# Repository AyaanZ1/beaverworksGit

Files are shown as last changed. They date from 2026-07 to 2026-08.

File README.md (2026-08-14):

# beaverworksGit

A maze-navigating robot built around an Arduino Mega 2560, combining custom
PCB design (KiCad) with firmware for grid-based autonomous navigation,
sensor logging, and ESP32-CAM video streaming.

## Overview

The robot drives through a 5x5 grid maze along a pre-defined path, correcting
its heading with an IMU (gyro yaw tracking) instead of relying on open-loop
timing alone. At each cell it pauses to read temperature, humidity, and
distance-to-obstacle, then reports the data back over serial. A light sensor
and buzzer provide simple flashlight/alarm behavior along the way, and a
separate ESP32-CAM module streams live video.

## Repository Structure

```
.
├── beaverworksGit.kicad_pro/.kicad_sch/.kicad_pcb  # KiCad project (schematic + PCB layout)
├── fp-lib-table                                    # KiCad footprint library table
├── hardware/                                        # Hardware design files
│   ├── beaverworksGit.kicad_*                       #   (duplicate/working copy of the KiCad project)
│   ├── Arduino Mega 2560 Rev3 A000067/               #   Arduino Mega 3D model + footprint
│   ├── Arduino_MountingHole.pretty/                  #   Mounting hole footprints
│   ├── HC-SR04 Model by SparkFun/                    #   Ultrasonic sensor 3D model + footprint
│   └── esp32-wrover-kicad-master/                    #   ESP32-WROVER KiCad library (third-party)
├── software/                                        # Firmware / companion scripts
│   ├── IMU Navigation/
│   │   ├── ObstacleAvoidance.ino                     #   Standalone obstacle-avoidance sketch
│   │   ├── Calibration/calibration.ino                #   IMU/gyro calibration routine
│   │   └── Yaw Tracking/mpu6050_copy_*/               #   MPU6050 yaw-tracking test sketch
│   ├── ESP32_Camera/                                 #   ESP32-CAM web server + streaming
│   │   ├── CameraWebServer.ino                        #     Main camera sketch (based on Espressif's CameraWebServer example)
│   │   ├── app_httpd.cpp / camera_pins.h / ...         #     Supporting camera server code
│   │   ├── wifi_secrets.example.h                     #     Template for Wi-Fi credentials (copy to wifi_secrets.h)
│   │   ├── record_video.py / stream_test.py            #     Python helpers for grabbing/testing the video stream
│   │   └── python/                                     #     Additional Python utilities
│   └── Sensors_Code/                                 #   (sensor test code)
├── main.cpp                                          # Main robot firmware: timed turns/drives, no gyro
├── navigatio.cpp                                     # Main robot firmware: gyro-corrected turns/drives (MPU6050)
└── platformio.ini                                    # PlatformIO project config (Arduino Mega target)
```

## Hardware

- **MCU:** Arduino Mega 2560 Rev3
- **IMU:** Adafruit MPU6050 (gyro-based yaw tracking)
- **Distance sensing:** HC-SR04 ultrasonic sensor
- **Environmental sensing:** DHT11 temperature/humidity sensor
- **Other I/O:** LDR (light sensor), sound sensor, buzzer, status LED
- **Drive:** Dual DC motors via an H-bridge driver (enable + direction pins per side)
- **Camera:** Separate ESP32-CAM module for live video streaming
- **PCB:** Custom board designed in KiCad (see `beaverworksGit.kicad_pro` / `hardware/`)

## Firmware

There are two versions of the main navigation firmware:

| File | Description |
|---|---|
| `main.cpp` | Drives a fixed sequence of grid moves using timed turns and timed straight-line driving (open-loop, no IMU feedback). |
| `navigatio.cpp` | Same grid path, but uses the MPU6050 gyro to track yaw in real time and correct heading while turning and driving (closed-loop). |

Both firmware versions:
1. Follow a hard-coded `path[]` array of `NORTH`/`EAST`/`SOUTH`/`WEST` moves through a 5x5 grid.
2. Stop at each cell to read temperature, humidity, and ultrasonic distance, and report them over serial.
3. Continuously monitor light and sound sensors to trigger an LED "flashlight" and buzzer alert.
4. Stop and idle once the path is complete.

### Building with PlatformIO

The project is set up for [PlatformIO](https://platformio.org/) targeting the Arduino Mega:

```bash
# Build
pio run

# Upload to the board
pio run -t upload

# Open the serial monitor (9600 baud)
pio device monitor
```

Dependencies (declared in `platformio.ini`):
- `adafruit/Adafruit MPU6050`
- `adafruit/Adafruit Unified Sensor`
- `adafruit/DHT sensor library`

> Note: only one of `main.cpp` / `navigatio.cpp` should be treated as the active
> `src/main.cpp` for a given build — move/copy whichever version you want to
> flash into PlatformIO's `src/` directory (or update `platformio.ini`'s
> `build_src_filter` accordingly).

### ESP32-CAM streaming

`software/ESP32_Camera/CameraWebServer.ino` is based on the standard Espressif
CameraWebServer example, adapted with local board/pin config. To use it:

1. Copy `wifi_secrets.example.h` to `wifi_secrets.h` and fill in your Wi-Fi
   SSID and password.
2. Flash `CameraWebServer.ino` to an ESP32-CAM board via the Arduino IDE
   (select the correct board and partition scheme — see `partitions.csv`).
3. Use `stream_test.py` or `record_video.py` to test/capture the resulting
   MJPEG stream from a computer on the same network.

### IMU navigation experiments

`software/IMU Navigation/` contains standalone sketches used during
development:
- `Calibration/calibration.ino` — computes gyro bias for the MPU6050.
- `Yaw Tracking/mpu6050_copy_*/` — isolated yaw-tracking test.
- `ObstacleAvoidance.ino` — simple reactive obstacle-avoidance behavior.

## Hardware Design (KiCad)

Open `beaverworksGit.kicad_pro` in [KiCad](https://www.kicad.org/) to view or
edit the schematic (`.kicad_sch`) and PCB layout (`.kicad_pcb`). Third-party
footprints/3D models used in the design are vendored under `hardware/`
(Arduino Mega, HC-SR04, ESP32-WROVER, mounting holes).

## Status

This is a work-in-progress class/competition project (Beaverworks). Firmware
constants such as `MS_PER_INCH`, `MS_PER_90_TURN`, drive speeds, and the
maze `path[]` are tuned for a specific physical maze layout and will need
recalibrating for a different course or robot chassis.

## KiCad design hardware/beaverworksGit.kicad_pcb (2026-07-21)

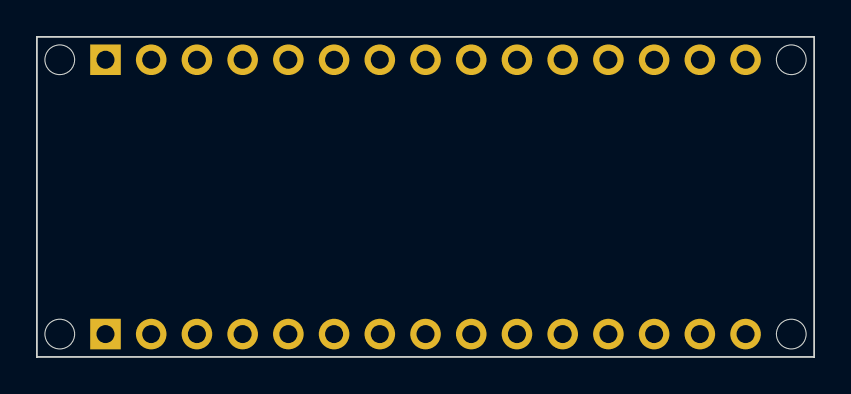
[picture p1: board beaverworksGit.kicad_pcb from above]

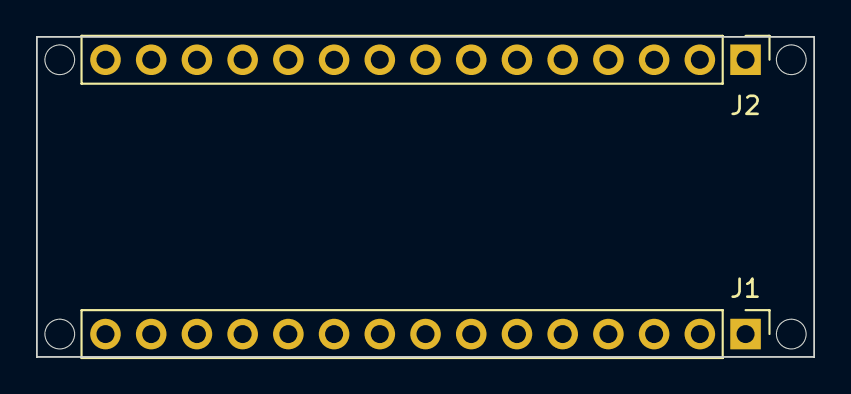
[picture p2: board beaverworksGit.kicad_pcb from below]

Board: 2 copper layers, 43.2 x 17.8 mm, 6 parts (2 on the bottom side), 2 nets, no tracks yet.

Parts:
J1: Analog; PinHeader_1x15_P2.54mm_Vertical
J2: Digital; PinHeader_1x15_P2.54mm_Vertical
MH1, MH2, MH3, MH4: MountingHole_65mil

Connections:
/~RESET: J1.13, J2.13
GND: J1.14, J2.12

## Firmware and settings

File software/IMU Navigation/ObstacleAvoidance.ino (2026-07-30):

#include <Arduino.h>
#include <Servo.h>

// ============================================================
// CONFIRMED MOTOR WIRING
// ============================================================
const byte LEFT_EN  = 2;
const byte LEFT_IN1 = 22;
const byte LEFT_IN2 = 23;

const byte RIGHT_EN  = 3;
const byte RIGHT_IN1 = 24;
const byte RIGHT_IN2 = 25;

// ============================================================
// ULTRASONIC + SERVO
// ============================================================
const byte TRIG_PIN  = 12;
const byte ECHO_PIN  = 13;
const byte SERVO_PIN = 4;   // Must not be pin 3

Servo scanServo;

// Change LEFT_ANGLE and RIGHT_ANGLE only if your servo is mounted backward.
const int LEFT_ANGLE    = 180;
const int CENTER_ANGLE  = 90;
const int RIGHT_ANGLE   = 0;

// ============================================================
// NAVIGATION SETTINGS
// ============================================================
const int DRIVE_SPEED = 150;
const int TURN_SPEED  = 150;

const int OBSTACLE_DISTANCE_CM = 25;
const int SIDE_CLEARANCE_CM    = 20;

// Calibrate this after basic behavior works.
const unsigned long TURN_90_TIME_MS = 650;
const unsigned long REVERSE_TIME_MS = 350;

const unsigned long SERVO_SETTLE_MS = 500;

// ============================================================
// MOTOR CONTROL
// Positive speed = forward
// Negative speed = reverse
// ============================================================
void setLeftMotor(int speed) {
  speed = constrain(speed, -255, 255);

  if (speed > 0) {
    digitalWrite(LEFT_IN1, HIGH);
    digitalWrite(LEFT_IN2, LOW);
  } else if (speed < 0) {
    digitalWrite(LEFT_IN1, LOW);
    digitalWrite(LEFT_IN2, HIGH);
  } else {
    digitalWrite(LEFT_IN1, LOW);
    digitalWrite(LEFT_IN2, LOW);
  }

  analogWrite(LEFT_EN, abs(speed));
}

void setRightMotor(int speed) {
  speed = constrain(speed, -255, 255);

  if (speed > 0) {
    digitalWrite(RIGHT_IN1, HIGH);
    digitalWrite(RIGHT_IN2, LOW);
  } else if (speed < 0) {
    digitalWrite(RIGHT_IN1, LOW);
    digitalWrite(RIGHT_IN2, HIGH);
  } else {
    digitalWrite(RIGHT_IN1, LOW);
    digitalWrite(RIGHT_IN2, LOW);
  }

  analogWrite(RIGHT_EN, abs(speed));
}

void moveForward() {
  setLeftMotor(DRIVE_SPEED);
  setRightMotor(DRIVE_SPEED);
}

void moveBackward() {
  setLeftMotor(-DRIVE_SPEED);
  setRightMotor(-DRIVE_SPEED);
}

void stopMotors() {
  setLeftMotor(0);
  setRightMotor(0);
}

void pivotLeft() {
  setLeftMotor(-TURN_SPEED);
  setRightMotor(TURN_SPEED);
}

void pivotRight() {
  setLeftMotor(TURN_SPEED);
  setRightMotor(-TURN_SPEED);
}

// ============================================================
// ULTRASONIC READING
// ============================================================
long singleDistanceReading() {
  digitalWrite(TRIG_PIN, LOW);
  delayMicroseconds(3);

  digitalWrite(TRIG_PIN, HIGH);
  delayMicroseconds(10);
  digitalWrite(TRIG_PIN, LOW);

  unsigned long duration = pulseIn(ECHO_PIN, HIGH, 30000UL);

  // No echo generally means nothing is nearby.
  if (duration == 0) {
    return 400;
  }

  long distanceCm = duration * 0.0343 / 2.0;

  if (distanceCm < 2 || distanceCm > 400) {
    return 400;
  }

  return distanceCm;
}

// Take three readings and return the median.
// This rejects many random HC-SR04 spikes.
long readDistanceCM() {
  long a = singleDistanceReading();
  delay(25);

  long b = singleDistanceReading();
  delay(25);

  long c = singleDistanceReading();

  if (a > b) {
    long temp = a;
    a = b;
    b = temp;
  }

  if (b > c) {
    long temp = b;
    b = c;
    c = temp;
  }

  if (a > b) {
    long temp = a;
    a = b;
    b = temp;
  }

  return b;
}

long lookAt(int angle) {
  scanServo.write(angle);
  delay(SERVO_SETTLE_MS);

  long distance = readDistanceCM();

  Serial.print("Servo angle ");
  Serial.print(angle);
  Serial.print(" -> ");
  Serial.print(distance);
  Serial.println(" cm");

  return distance;
}

// ============================================================
// TURNING
// ============================================================
void turnLeft90() {
  Serial.println("ACTION: TURN LEFT");

  pivotLeft();
  delay(TURN_90_TIME_MS);

  stopMotors();
  delay(250);
}

void turnRight90() {
  Serial.println("ACTION: TURN RIGHT");

  pivotRight();
  delay(TURN_90_TIME_MS);

  stopMotors();
  delay(250);
}

// ============================================================
// OBSTACLE AVOIDANCE
// ============================================================
void avoidObstacle() {
  stopMotors();
  delay(250);

  Serial.println();
  Serial.println("OBSTACLE DETECTED — SCANNING");

  long leftDistance = lookAt(LEFT_ANGLE);
  long rightDistance = lookAt(RIGHT_ANGLE);

  scanServo.write(CENTER_ANGLE);
  delay(SERVO_SETTLE_MS);

  Serial.print("LEFT: ");
  Serial.print(leftDistance);
  Serial.print(" cm | RIGHT: ");
  Serial.print(rightDistance);
  Serial.println(" cm");

  bool leftBlocked = leftDistance <= SIDE_CLEARANCE_CM;
  bool rightBlocked = rightDistance <= SIDE_CLEARANCE_CM;

  // Both sides blocked: back away, then turn toward the larger opening.
  if (leftBlocked && rightBlocked) {
    Serial.println("Both sides blocked — reversing");

    moveBackward();
    delay(REVERSE_TIME_MS);
    stopMotors();
    delay(200);
  }

  // Turn toward the side with MORE space.
  if (leftDistance > rightDistance) {
    turnLeft90();
  } else {
    turnRight90();
  }

  // Always center the sensor after turning.
  scanServo.write(CENTER_ANGLE);
  delay(250);
}

// ============================================================
// SETUP
// ============================================================
void setup() {
  Serial.begin(9600);

  pinMode(LEFT_EN, OUTPUT);
  pinMode(LEFT_IN1, OUTPUT);
  pinMode(LEFT_IN2, OUTPUT);

  pinMode(RIGHT_EN, OUTPUT);
  pinMode(RIGHT_IN1, OUTPUT);
  pinMode(RIGHT_IN2, OUTPUT);

  pinMode(TRIG_PIN, OUTPUT);
  pinMode(ECHO_PIN, INPUT);

  stopMotors();

  scanServo.attach(SERVO_PIN);
  scanServo.write(CENTER_ANGLE);

  delay(1500);

  Serial.println("Obstacle avoidance started.");
}

// ============================================================
// MAIN LOOP
// ============================================================
void loop() {
  scanServo.write(CENTER_ANGLE);

  long frontDistance = readDistanceCM();

  Serial.print("FRONT: ");
  Serial.print(frontDistance);
  Serial.println(" cm");

  if (frontDistance > OBSTACLE_DISTANCE_CM) {
    moveForward();
  } else {
    avoidObstacle();
  }

  delay(60);
}

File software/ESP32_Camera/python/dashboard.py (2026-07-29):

import time
from collections import deque
from pathlib import Path

import cv2
import streamlit as st
import pandas as pd
import requests
from ultralytics import YOLO


STREAM_URL = "http://192.168.1.4:81/stream"
CELL_URL = "http://192.168.1.4/cell"
MODEL_PATH = Path(__file__).parent / "yolo26n.pt"

TARGET_CLASS = "person"
CONFIRMATION_FRAMES = 3
TARGET_LOSS_DELAY = 0.75

HEAT_HAZARD_THRESHOLD_C = 35.0

IMAGE_DIRECTORY = Path(__file__).parent / "cell_images"
IMAGE_DIRECTORY.mkdir(parents=True, exist_ok=True)

CELL_POLL_INTERVAL = 0.5


st.set_page_config(
    page_title="Autonomous Robot Dashboard",
    page_icon="🤖",
    layout="wide",
)

if "detection_log" not in st.session_state:
    st.session_state.detection_log = []

if "selected_cell_id" not in st.session_state:
    st.session_state.selected_cell_id = 1

if "last_reported_cell_id" not in st.session_state:
    st.session_state.last_reported_cell_id = None

if "pending_capture_cell_id" not in st.session_state:
    st.session_state.pending_capture_cell_id = None


def create_empty_cell_data():
    """Create 16 empty cells that are populated by live ESP32 readings."""
    cells = {}

    for cell_id in range(1, 17):
        cells[cell_id] = {
            "id": cell_id,
            "tempC": None,
            "heatHazard": False,
            "humidity": None,
            "distanceCm": None,
            "soundLevel": None,
            "soundHazard": False,
            "ok": True,
            "visited": False,
            "latest_image": None,
            "objects": [],
        }

    return cells
def format_reading(value, decimals=1, suffix=""):
    """Display unavailable sensor readings as --."""
    if value is None:
        return "--"

    return f"{value:.{decimals}f}{suffix}"


def format_temperature(temp_c):
    """Display temperature in Celsius and Fahrenheit."""
    if temp_c is None:
        return "--"

    temp_f = temp_c * 9 / 5 + 32
    return f"{temp_c:.1f}°C ({temp_f:.1f}°F)"


def update_live_cell_data():
    """Fetch the newest environmental reading from the ESP32."""

    try:
        response = requests.get(CELL_URL, timeout=0.25)

        if response.status_code != 200:
            return

        live = response.json()

        cell_id = live["id"]

        if cell_id not in st.session_state.cell_data:
            return

        st.session_state.cell_data[cell_id].update(
            {
                "id": cell_id,
                "tempC": live["tempC"],
                "heatHazard": (
                    live["tempC"] is not None
                    and live["tempC"] >= HEAT_HAZARD_THRESHOLD_C
                ),
                "humidity": live["humidity"],
                "distanceCm": live["distanceCm"],
                "soundLevel": live.get("soundLevel"),
                "soundHazard": live.get("soundHazard", False),
                "ok": live["ok"],
                "visited": True,
            }
        )

        if cell_id != st.session_state.last_reported_cell_id:
            st.session_state.last_reported_cell_id = cell_id
            st.session_state.pending_capture_cell_id = cell_id

    except Exception:
        pass


if "cell_data" not in st.session_state:
    st.session_state.cell_data = create_empty_cell_data()
update_live_cell_data()

st.title("🤖 Autonomous Robot Dashboard")
st.caption("Real-time perception, navigation, and environmental monitoring")


@st.cache_resource
def load_model(model_path: str) -> YOLO:
    return YOLO(model_path)


def choose_command(
    center_x: float,
    frame_width: int,
    box_width: float,
) -> str:
    left_boundary = frame_width * 0.40
    right_boundary = frame_width * 0.60
    width_ratio = box_width / frame_width

    if width_ratio > 0.55:
        return "STOP"

    if center_x < left_boundary:
        return "TURN_LEFT"

    if center_x > right_boundary:
        return "TURN_RIGHT"

    return "FORWARD"


if not MODEL_PATH.exists():
    st.error(f"Model not found: {MODEL_PATH}")
    st.stop()

model = load_model(str(MODEL_PATH))

st.sidebar.header("Controls")

confidence_threshold = st.sidebar.slider(
    "Detection confidence",
    min_value=0.10,
    max_value=1.00,
    value=0.20,
    step=0.05,
)

target_class = st.sidebar.text_input(
    "Target object",
    value=TARGET_CLASS,
).strip().lower()

start_camera = st.sidebar.toggle(
    "Start ESP32-CAM",
    value=False,
)

st.sidebar.code(STREAM_URL)

video_column, status_column = st.columns([3, 1])

with video_column:
    st.subheader("Live Camera Feed")
    video_placeholder = st.empty()

with status_column:
    st.subheader("System Status")
    camera_status = st.empty()
    detection_status = st.empty()
    command_status = st.empty()
    fps_status = st.empty()

    st.subheader("Target Tracking")
    target_status = st.empty()
    track_status = st.empty()
    confidence_status = st.empty()
    position_status = st.empty()

st.subheader("Detection History")
history_placeholder = st.empty()
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

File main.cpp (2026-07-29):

#include <Arduino.h>
#include <DHT.h>


#define DHTPIN 33
#define DHTTYPE DHT11
#define LED_PIN 8
#define LDR_PIN A3
#define SOUND_PIN A0
#define BUZZER_PIN 9
#define TRIG_PIN 12
#define ECHO_PIN 13

DHT dht(DHTPIN, DHTTYPE);
const int DARK_THRESHOLD = 400;
const int SOUND_THRESHOLD = 500;


#define LEFT_EN    2
#define LEFT_IN1   22
#define LEFT_IN2   23
#define RIGHT_EN   3
#define RIGHT_IN1  24
#define RIGHT_IN2  25

const int DRIVE_SPEED = 150;
const int TURN_SPEED  = 120;

const float CELL_SIZE_IN = 10.0;
const int GRID_WIDTH = 5;

// ---- Timing calibration constants ----

float MS_PER_INCH = 95.0;          //time to drive one inch
unsigned long MS_PER_90_TURN = 500; // time to pivot-turn 90 degrees

enum Direction { NORTH, EAST, SOUTH, WEST };

Direction path[] = {
  NORTH, NORTH, WEST, SOUTH, SOUTH, WEST, WEST, WEST, NORTH, NORTH,
  EAST,  SOUTH, EAST, NORTH, NORTH, EAST, EAST, NORTH, WEST, WEST,
  WEST,  SOUTH, WEST, NORTH
};
const int pathLength = sizeof(path) / sizeof(path[0]);

Direction currentHeading = NORTH;
int gridX = 4;
int gridY = 4;

void updateFlashlightAndSound();
void setMotors(int leftSpeed, int rightSpeed);
void stopMotors();
void turnToHeading(Direction target);
void driveOneCell();
void executeMove(Direction next);
void updateGridPosition(Direction d);
int cellID(int x, int y);
void pauseAndReadCell();
long readUltrasonic();
void reportCellData(int id, float tempC, float humidity, long distanceCm);

void setup() {
  Serial.begin(9600);
  Serial1.begin(9600);

  dht.begin();
  pinMode(LED_PIN, OUTPUT);
  pinMode(LDR_PIN, INPUT);
  pinMode(SOUND_PIN, INPUT);
  pinMode(BUZZER_PIN, OUTPUT);
  pinMode(TRIG_PIN, OUTPUT);
  pinMode(ECHO_PIN, INPUT);

  pinMode(LEFT_IN1, OUTPUT);
  pinMode(LEFT_IN2, OUTPUT);
  pinMode(LEFT_EN, OUTPUT);
  pinMode(RIGHT_IN1, OUTPUT);
  pinMode(RIGHT_IN2, OUTPUT);
  pinMode(RIGHT_EN, OUTPUT);

  Serial.println("Starting navigation (no gyro, timed turns/drives).");
  delay(1000);
}

void loop() {
  static int step = 0;

  updateFlashlightAndSound();

  if (step < pathLength) {
    executeMove(path[step]);
    pauseAndReadCell();
    step++;
  } else {
    stopMotors();
    Serial.println("Path complete. Robot stopped at final cell.");
    while (1) {
      updateFlashlightAndSound();
    }
  }
}

void updateFlashlightAndSound() {
  int lightLevel = analogRead(LDR_PIN);
  if (lightLevel < DARK_THRESHOLD) {
    digitalWrite(LED_PIN, HIGH);
  } else {
    digitalWrite(LED_PIN, LOW);
  }

  int soundLevel = analogRead(SOUND_PIN);
  if (soundLevel > SOUND_THRESHOLD) {
    tone(BUZZER_PIN, 1000, 200);
  }
}

void setMotors(int leftSpeed, int rightSpeed) {
  digitalWrite(LEFT_IN1, leftSpeed >= 0 ? HIGH : LOW);
  digitalWrite(LEFT_IN2, leftSpeed >= 0 ? LOW : HIGH);
  analogWrite(LEFT_EN, abs(leftSpeed));

  digitalWrite(RIGHT_IN1, rightSpeed >= 0 ? HIGH : LOW);
  digitalWrite(RIGHT_IN2, rightSpeed >= 0 ? LOW : HIGH);
  analogWrite(RIGHT_EN, abs(rightSpeed));
}

void stopMotors() {
  analogWrite(LEFT_EN, 0);
  analogWrite(RIGHT_EN, 0);
  digitalWrite(LEFT_IN1, LOW);
  digitalWrite(LEFT_IN2, LOW);
  digitalWrite(RIGHT_IN1, LOW);
  digitalWrite(RIGHT_IN2, LOW);
}


void turnToHeading(Direction target) {
  int diff = ((int)target - (int)currentHeading + 4) % 4; 

  if (diff == 0) return; 

  for (int i = 0; i < diff; i++) {
    setMotors(TURN_SPEED, -TURN_SPEED); 
    delay(MS_PER_90_TURN);
    stopMotors();
    delay(150); 
  }
}

void driveOneCell() {
  unsigned long driveTimeMs = (unsigned long)(CELL_SIZE_IN * MS_PER_INCH);

  setMotors(255, 255); 
  delay(40);

  setMotors(DRIVE_SPEED, DRIVE_SPEED);
  delay(driveTimeMs);

  stopMotors();
}

void executeMove(Direction next) {
  turnToHeading(next);
  driveOneCell();
  currentHeading = next;
  updateGridPosition(next);
}

void updateGridPosition(Direction d) {
  if (d == NORTH) gridY--;
  if (d == SOUTH) gridY++;
  if (d == EAST)  gridX++;
  if (d == WEST)  gridX--;
}

int cellID(int x, int y) {
  return (GRID_WIDTH * GRID_WIDTH) - (y * GRID_WIDTH + x);
}

void pauseAndReadCell() {
  int id = cellID(gridX, gridY);

  float humidity = dht.readHumidity();
  float tempC = dht.readTemperature();
  long distance = readUltrasonic();

  reportCellData(id, tempC, humidity, distance);

  unsigned long startTime = millis();
  while (millis() - startTime < 2000) {
    updateFlashlightAndSound();
    delay(20);
  }
}

long readUltrasonic() {
  digitalWrite(TRIG_PIN, LOW);
  delayMicroseconds(2);
  digitalWrite(TRIG_PIN, HIGH);
  delayMicroseconds(10);
  digitalWrite(TRIG_PIN, LOW);

  long duration = pulseIn(ECHO_PIN, HIGH, 30000);
  if (duration == 0) return -1;

  long distance = duration * 0.034 / 2;
  return distance;
}

void reportCellData(int id, float tempC, float humidity, long distanceCm) {
  if (isnan(tempC) || isnan(humidity)) {
    Serial.print("Cell "); Serial.print(id);
    Serial.println(": DHT11 read failed.");
    return;
  }

  Serial.print("Cell "); Serial.print(id);
  Serial.print(" | Temp: "); Serial.print(tempC);
  Serial.print(" C | Humidity: "); Serial.print(humidity);
  Serial.print(" % | Ultrasonic: "); Serial.print(distanceCm);
  Serial.println(" cm");
}

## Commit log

2026-07-21 First prototype
    [beaverworksGit.kicad_pcb, beaverworksGit.kicad_sch]
2026-07-21 Added MPU6050 IMU navigation subsystem
2026-07-22 Add ESP32 camera web server
    [partitions.csv]
2026-07-22 Add ALL sensors
2026-07-23 Add ESP32 camera vision pipeline and YOLO detection
2026-07-23 Add live YOLO inference for ESP32 camera stream
2026-07-23 fix: remove embedded git repository and added hopefully updated wire diagram with everytying except the esp32
    [beaverworksGit.kicad_pcb, beaverworksGit.kicad_sch]
2026-07-24 Complete ESP32 vision tracking and monitoring dashboard
2026-07-28 hello these are hopefully with serial connections should work if not revert to old
    [CameraWebServer.ino, dashboard.py, navigatio.cpp]
2026-07-29 Added it so that the data is all in one webserver (go to /live for el data) it shoudl work just turn off site protections in chrome://settings/security
2026-07-29 Navigation timer based with no MPU
2026-07-29 Add heat hazard monitoring with Celsius and Fahrenheit display
2026-07-30 Added ultrasonic obstacle avoidance navigation
    [ObstacleAvoidance.ino]
